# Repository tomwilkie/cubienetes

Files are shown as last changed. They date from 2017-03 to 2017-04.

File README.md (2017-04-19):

# Cubienetes: A Kubernetes Cluster on Cubieboard2s

This is a project to build a home 5-node Kubernetes cluster using Cubieboards.

## Parts

- 5 x [Cubieboard2](https://www.amazon.co.uk/dp/B00FB5ILQ4) £48.95
- 1 x [NETGEAR GS108UK 8-Port Gigabit Ethernet Unmanaged Switch](https://www.amazon.co.uk/gp/product/B0000E5SES) £24.97
- 1 x [Anker 40W 5-Port USB Charger](https://www.amazon.co.uk/dp/B00EJA28ES)
- 5 x [Short Black 0.25M Ethernet Cable](https://www.amazon.co.uk/gp/product/B00E7B1K2A) £1.81
- 1 x [Kingston MobileLite G4 USB 3.0 Multi Card Reader](https://www.amazon.co.uk/gp/product/B00KX4TORI) £7.12
- 2 x [1000mm M3 threaded rod](https://www.amazon.co.uk/gp/product/B01F3RLO8Q) £2.54
- 2 x [M3 Full Nut (50 Pack)](https://www.amazon.co.uk/gp/product/B00A6G3G2C) £1.40
- 2 x [M3 Washer 3.2mm (50 Pack)](https://www.amazon.co.uk/gp/product/B00A6PGHC4) £1.65
- 10 x [Custom 3D-printed HD brackets](https://www.shapeways.com/product/WRM3XQTWM/hdbracket) £3.50
- 5 x [Transcend 128GB SATA III SSD360 128GB](https://www.amazon.co.uk/dp/B018HW0EA8) £56.50

## Assembly

First versions of the hard disk brackets didn't quite fit:

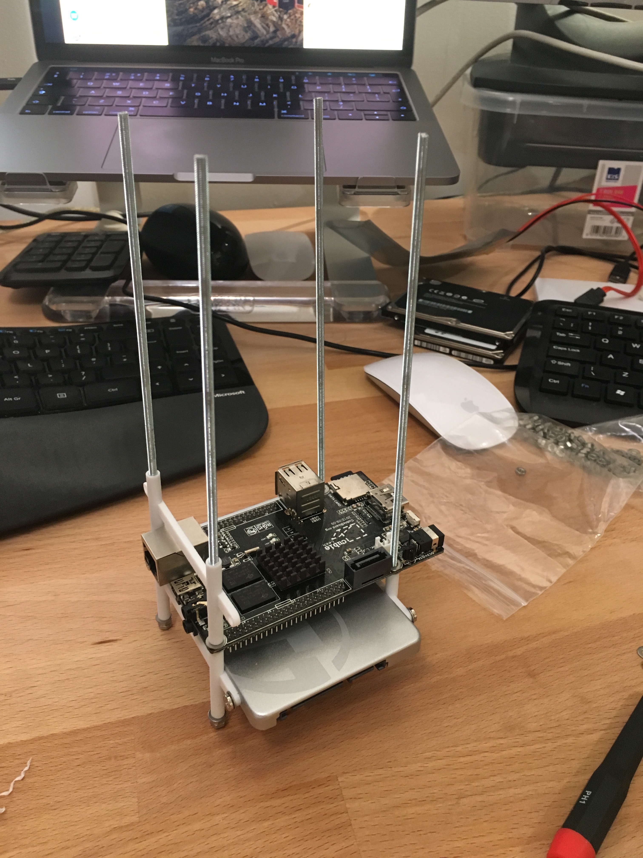
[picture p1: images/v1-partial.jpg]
First partial assembly


I did a full build to get a handle on the cabling too:

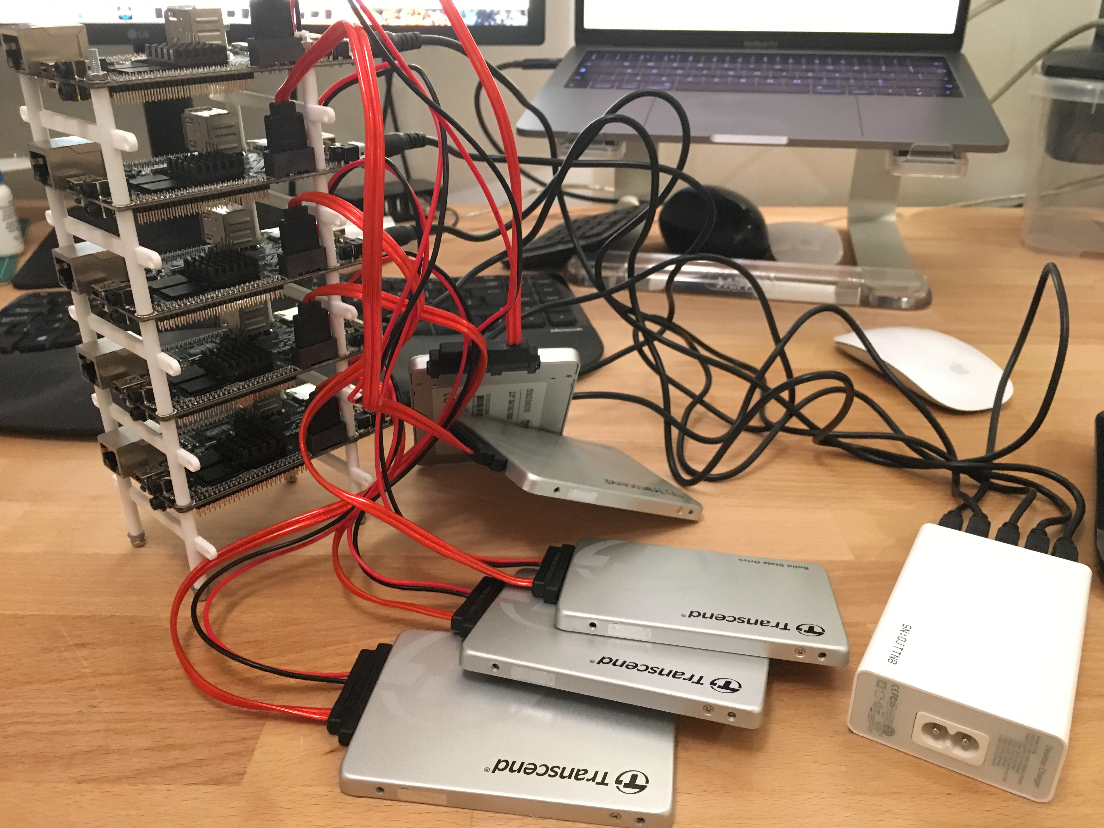
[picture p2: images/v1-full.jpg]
First full assembly


Problems were:
- The SSD mounting hole pitch was off by 0.5mm.
- The walls around the pillars meant the distance between the pillars was too small.
- The bore of all the holes (3mm) was too tight for M3 threaded rod and needed drilling out.  Surprisingly the Shapeways white plastic took this quite well.

So I created & new design and ordered that:

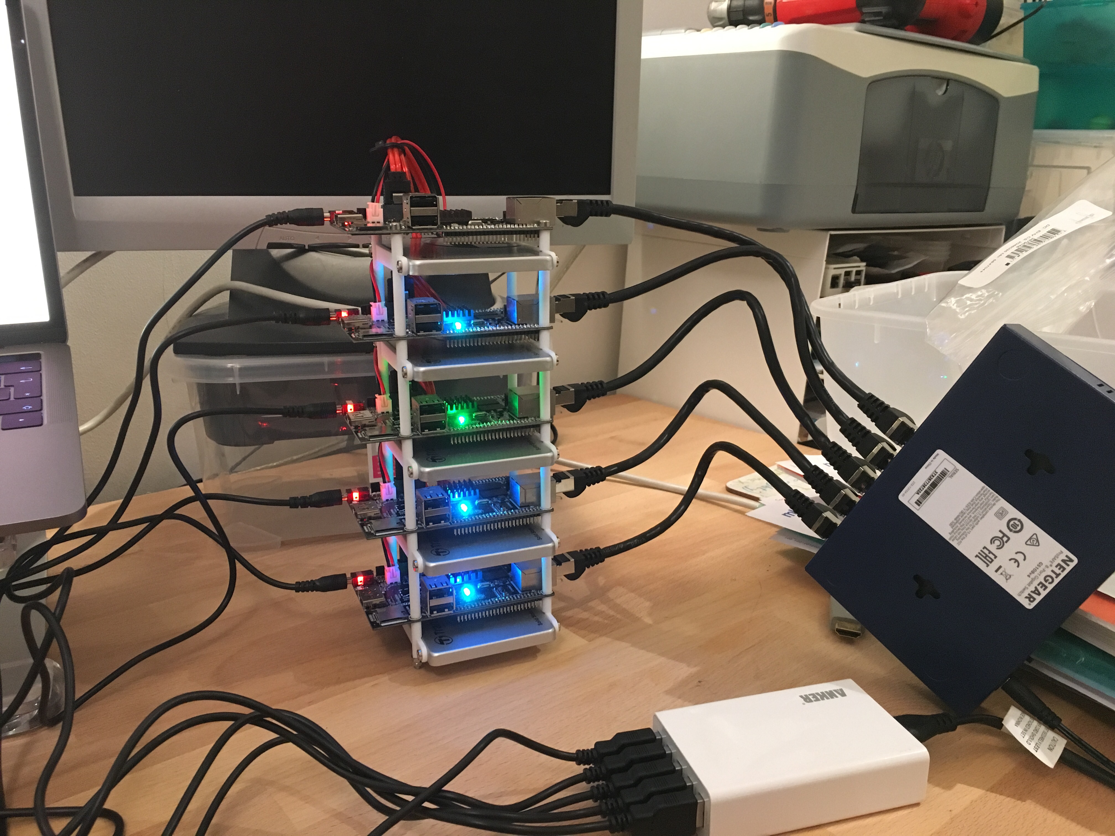
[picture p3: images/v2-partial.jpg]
Second partial assembly


And with the router & PSU double-sided-sticky taped on, and cables all cable-tied:

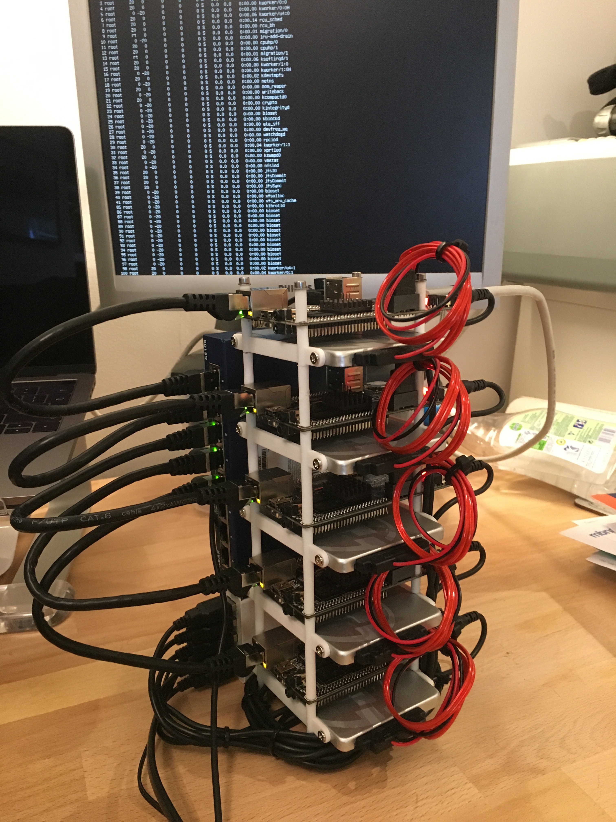
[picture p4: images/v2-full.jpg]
Second full assembly


## Software

### Operating System

- Used Debian Jessie from https://www.armbian.com/cubieboard-2/
- Use [Keka](http://www.kekaosx.com/en/) and [Etcher](https://etcher.io/) to decompress / write the image.
- Use the latest kernel you can - Docker needs it.

### Manual setup

For ansible to work, I setup password-less ssh:

```
mkdir .ssh
chmod 700 ~/.ssh
echo "<REDACTED>" > ~/.ssh/authorized_keys
chmod 600 ~/.ssh/authorized_keys
```

I did this manually.  I also statically assigned IP addresses 192.168.0.1-5 to the Cubieboards manually.  The rest was configured with ansible.

### Automated setup

I designated the first Cubieboard as the "master", and set it up to do NAT routing & DNS as it also has a WiFi adapter.

```
ansible-playbook --inventory-file=inventory --user=root custom-playbooks/networking.yaml
```

The disks got LVM & ext4 installed and mounted at /mnt/countainers:

```
ansible-playbook --inventory-file=inventory --user=root custom-playbooks/disks.yaml
```

And the hostnames were all set and put in /etc/hosts:

```
ansible-playbook --inventory-file=inventory --user=root custom-playbooks/hostname.yaml
```

### Docker Daemon

- Used [Hypriot's instructions](http://blog.hypriot.com/post/family_arm_hardware_for_docker_more_children/)
- https://packagecloud.io/app/Hypriot/Schatzkiste/search?filter=all&q=docker-hypriot&dist=debian%2Fjessie

```
ansible-playbook --inventory-file=inventory --user=root custom-playbooks/docker.yaml
```

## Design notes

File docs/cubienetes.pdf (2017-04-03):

https://github.com/tomwilkie/cubienetes | 29 March 2017

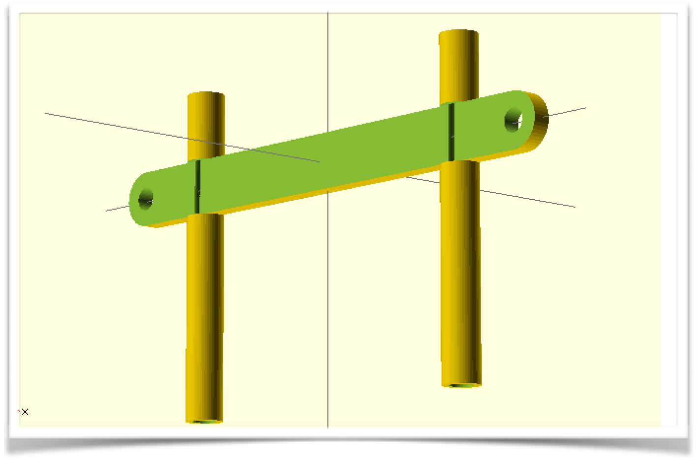
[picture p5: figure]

## K8s on Cubieboard2

A 5-node Kubernetes cluster running on Cubieboard2.

5 x Cubieboard2 £48.95
1 x NETGEAR GS108UK 8-Port Gigabit Ethernet Unmanaged Switch £24.97
1 x Anker 40W 5-Port USB Charger

5 x Short Black 0.25M Ethernet Cable £1.81

1 x Kingston MobileLite G4 USB 3.0 Multi Card Reader £7.12 2 x 1000mm M3 threaded rod £2.54

2 x M3 Full Nut (50 Pack) £1.40
2 x M3 Washer 3.2mm (50 Pack) £1.65

10 x Custom 3D-printed HD brackets £3.50

5 x Transcend 128GB SATA III SSD360 128GB £56.50

1

Cubieboard2

I chose the Cubieboard2 as it comes with SATA and gigabit ethernet. It is a dual-core
ARM7 chip (and Allwinner
A20) with 1GB of RAM. There a 4GB NAND flash MTD device on the back.

3d Printed brackets

The brackets were designed in OpenSCAD and 3D printer on Shapeways.

Ansible

The GitHub repo https://
github.com/tomwilkie/
cubienetes (https://github.com/tomwilkie/cubienetes) has ansible
playbooks for provisioning the cluster with docker, kubernetes etc

NAT routing & WiFi

The top board has a WiFi
dongle and is configured to do NAT, DHCP & DNS for the
other boards, so they all have internet access. Which is
useful for installing packages.

# CUBIENETES

# #APPOPS #DEVOPELMENT

https://github.com/tomwilkie/cubienetes | 29 March 2017

2

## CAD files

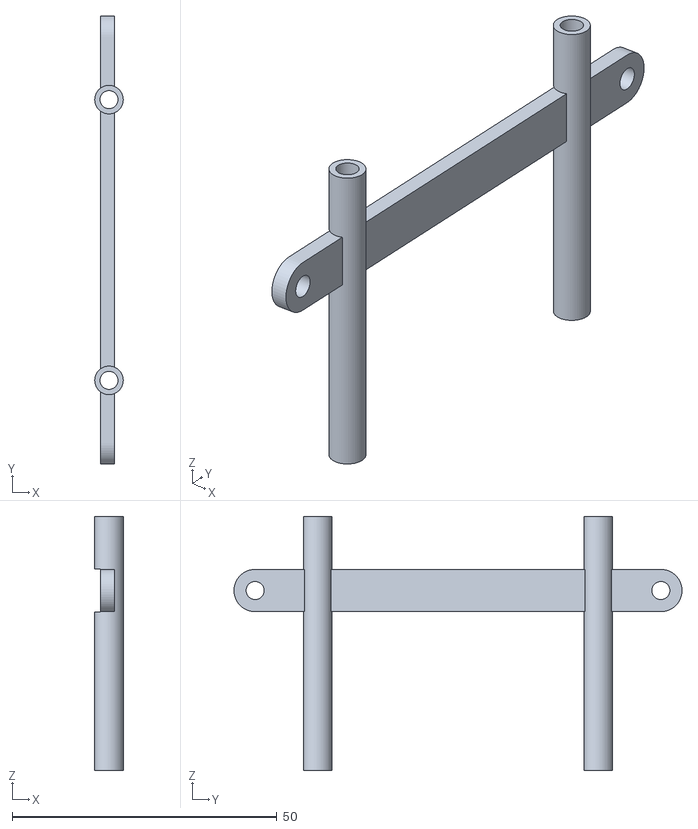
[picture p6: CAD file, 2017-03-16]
hdbrackets/hdbracket2.stl
5.40 x 84.6 x 48.0

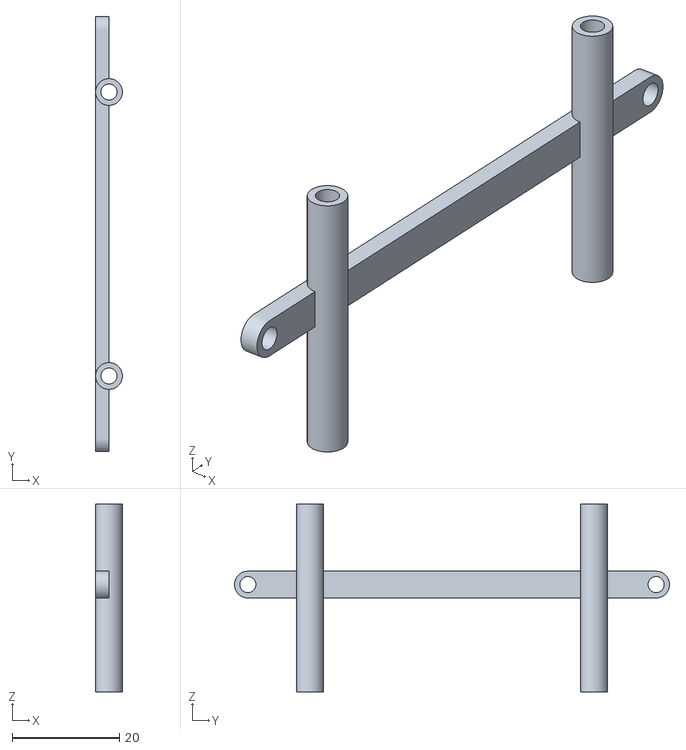
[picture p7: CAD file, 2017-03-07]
hdbrackets/hdbracket.stl
5.00 x 81.2 x 35.0

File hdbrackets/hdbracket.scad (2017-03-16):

// all in mm
cubieboard_pitch = 53;
ssd_pitch        = 76.6;
ssd_height       = 8;
material         = 1;
hole_diameter    = 3.4;
standoff_height  = 30 + ssd_height + 10;
u                = 10;
$fn              = 50;
height           = (2 * material) + hole_diameter;

difference() {
	union() {
		translate(v = [
			-height/2-hole_diameter/2, 
			-ssd_pitch/2, 
			-ssd_height/2,
		]) {
			cube([height, ssd_pitch, ssd_height]);
		}
	
		translate(v = [
			0, 
			-cubieboard_pitch/2, 
			-30-(ssd_height/2),
		]) {
			cylinder(h=standoff_height, r=height/2);
		}
	
		translate(v = [
			0, 
			cubieboard_pitch/2, 
			-30-(ssd_height/2),
		]) {
			cylinder(h=standoff_height, r=height/2);
		}

		translate(v = [
			-height/2-hole_diameter/2, 
			-ssd_pitch/2, 
			0,
		]) {
			rotate(a = [0, 90, 0]) { 		
				cylinder(h=height, r=ssd_height/2);
			}
		}

		translate(v = [
			-height/2-hole_diameter/2, 
			ssd_pitch/2, 
			0,
		]) {
			rotate(a = [0, 90, 0]) { 		
				cylinder(h=height, r=ssd_height/2);
			}
		}
	}

	union() {
		translate(v = [
			0, 
			-cubieboard_pitch/2, 
			-30-(ssd_height+u)/2,
		]) {
			cylinder(h=standoff_height+u, r=hole_diameter/2);
		}

		translate(v = [
			0, 	
			cubieboard_pitch/2, 
			-30-(ssd_height+u)/2,
		]) {
			cylinder(h=standoff_height+u, r=hole_diameter/2);
		}


		translate(v = [
			-height/2-hole_diameter/2, 
			-ssd_pitch/2, 
			0,
		]) {
			rotate(a = [0, 90, 0]) { 		
				cylinder(h=height+u/2, r=hole_diameter/2);
			}
		}

		translate(v = [
			-height/2-hole_diameter/2, 
			ssd_pitch/2, 
			0,
		]) {
			rotate(a = [0, 90, 0]) { 		
				cylinder(h=height+u/2, r=hole_diameter/2);
			}
		}

		translate(v = [
			-height-hole_diameter/2+0.1,
			(-ssd_pitch-u)/2, 
			-(ssd_height+0.1)/2,
		]) {
			cube([height, ssd_pitch+u, ssd_height+0.1]);
		}
	}
}

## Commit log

2017-03-07 Initial commit: HD bracket design and README.md
    [hdbracket.scad, hdbracket.stl]
2017-03-16 v2 of the brackets
    [hdbracket.scad, hdbracket2.stl]
